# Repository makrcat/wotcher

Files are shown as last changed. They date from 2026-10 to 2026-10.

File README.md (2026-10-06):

## wotcher


wotcher is a digital raise-to-wake LED watch, with 89 LEDs in total! It uses something called charlieplexing to make all the lights glow at once. 

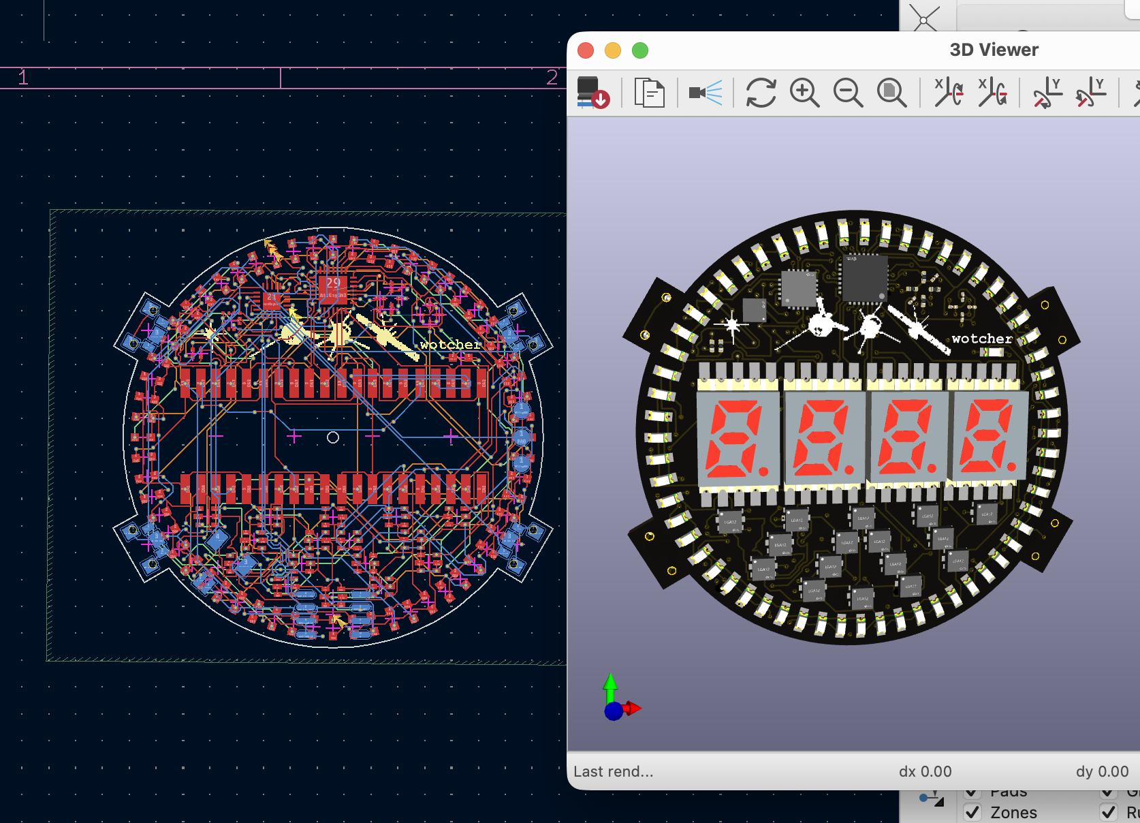
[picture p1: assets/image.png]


## circuit design
Charlieplexing is a method to limit current & control many LED's with only a couple of microcontroller pins, by switching between LEDs really fast so it looks like they're always on, due to the phenomenon of persistence of vision.

- My project uses a charlieplexing chip (IS31FL3731-QF) to drive the 7-segment display & all 60 LEDs, which is 88 LEDs in total. 
- The clock chip (DS3231MZ+) is necessary here because the ATtiny's internal RC oscillator clock is terrible at time keeping. The clock chip only drifts like 2 seconds a year! So that's cool.
- I'm also including an accelerometer so that it's raise-to-wake, like those Apple watches.

# some inspiration

It's inspired by various retro-style watches, such as the aptly named retrowatch, the charlie watch, and the decko circuit face watch, as well as other pinterest pictures.

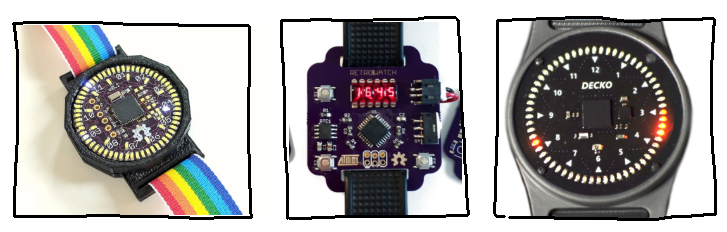
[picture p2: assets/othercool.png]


<i>from left to right, <a src="https://trmm.net/Charliewatch/">charliewatch</a>, <a src="https://github.com/RafaelRiber/RetroWatch">retrowatch</a>, decko (by the Terminelectro company)</i>

## features

I'm going to use embedded c++ to code this later, when I get my breadboard components.

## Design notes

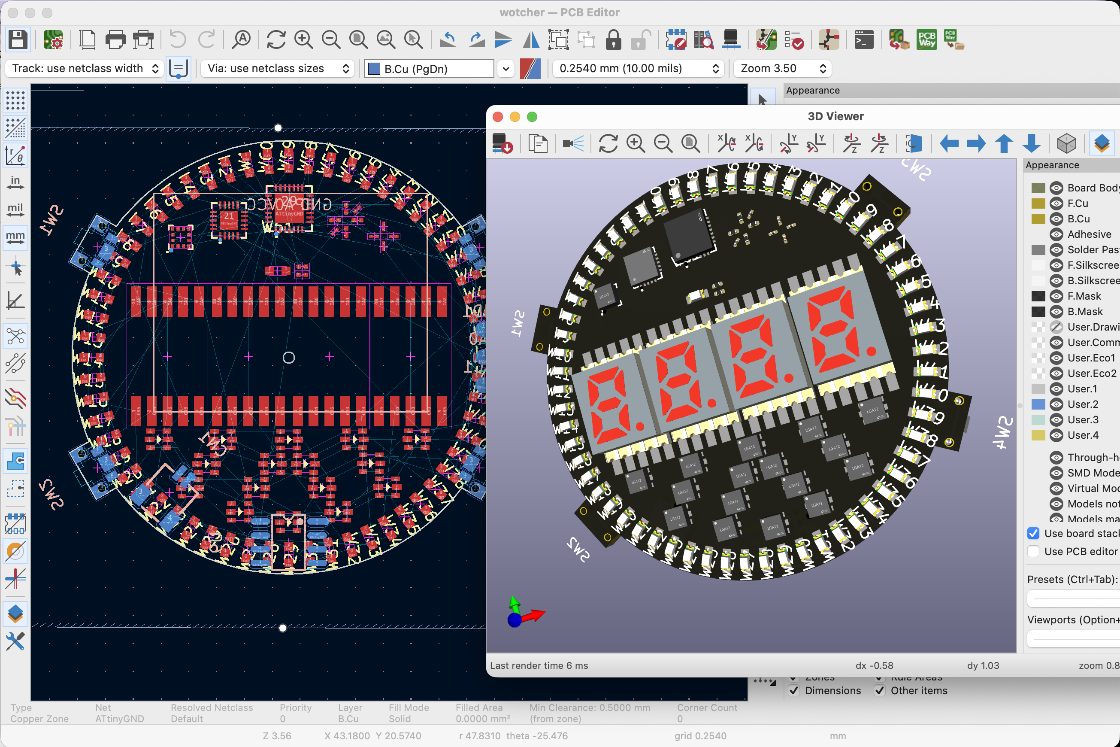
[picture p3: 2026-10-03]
assets/3ded.png

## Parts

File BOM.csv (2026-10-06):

Category | Item Name | Qty | Price (total) (USD) | Item link | Notes
Prototyping | LED Matrix | 1 | $7.50 | https://www.digikey.com/en/products/detail/adafruit-industries-llc/2947/5959341 | Buying an LED Matrix to prototype test the 60 LEDs
 | 3731 driver | 1 | $5.95 | https://www.digikey.com/en/products/detail/adafruit-industries-llc/2946/5959340
 | clock oscillator | 1 | $6.90 | https://www.dfrobot.com/product-1991.html | can I pay for shipping
 | ATtiny1616 breakout | 1 | $4.95 | https://www.digikey.com/en/products/detail/adafruit-industries-llc/5690/18627499?_gl=1*1cuqnpn*_up*MQ..*_gs*MQ..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 | breakout
 | 7-segment | 4 | $11.64 | https://www.digikey.com/en/products/detail/kingbright/ACSA02-41SURKWA-F01/2163665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..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 | through hole, it's not the same one but for testing
 | soldering paste for the bottom | 4 | $8.99 | https://www.amazon.com/Clean-Lead-Solder-Paste-Grams/dp/B017RTTR14 | for the bottom
 | pogo pin clip | 1 | $10.95 | https://www.digikey.com/en/products/detail/adafruit-industries-llc/5433/16584075
 | flux paste | 1 | $9.99 | https://www.amazon.com/Wonderway-Soldering-Electronics-CELLPHONE-Repairing/dp/B0BNKKRYK9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
JLCPCB assembly | everything assembly | 1 | $129.32 | $108.18+ $0.9153 * 5
 | Total Price (USD): | $196.19

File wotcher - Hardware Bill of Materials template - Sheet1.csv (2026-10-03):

Category | Item Name | Qty | Price (total) (USD) | Item link | Notes
Prototyping | LED Matrix | 1 | $7.50 | https://www.digikey.com/en/products/detail/adafruit-industries-llc/2947/5959341 | Buying an LED Matrix to prototype test the 60 LEDs
 | 3731 driver | 1 | $5.95 | https://www.digikey.com/en/products/detail/adafruit-industries-llc/2946/5959340
 | clock oscillator | 1 | $13.89 | https://www.dfrobot.com/product-1991.html | breakout for clock? the cheapest shipping also is 7 typically. so 6.9 + 6.99 ish
 | ATtiny1616 breakout | 1 | $4.95 | https://www.digikey.com/en/products/detail/adafruit-industries-llc/5690/18627499?_gl=1*1cuqnpn*_up*MQ..*_gs*MQ..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 | breakout
 | 7-segment | 4 | $11.64 | https://www.digikey.com/en/products/detail/kingbright/ACSA02-41SURKWA-F01/2163665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..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
 | soldering paste for the bottom | 4 | $8.99 | https://www.amazon.com/Clean-Lead-Solder-Paste-Grams/dp/B017RTTR14 | for the bottom
 | pogo pin clip | 1 | $10.95 | https://www.digikey.com/en/products/detail/adafruit-industries-llc/5433/16584075
 | flux paste | 1 | $9.99 | https://www.amazon.com/Wonderway-Soldering-Electronics-CELLPHONE-Repairing/dp/B0BNKKRYK9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
 | shipping | 1 | $6.00 |  | shipping of everything from digikey
 | soldering wire 1.5mm | 1 | $5.99 | amazon.com/Twocorn-no-wash-tin-Lead-Electric-Soldering/dp/B0CP7QHFL6/ref=sr_1_2?crid=3EKAVLY062JCC&dib=eyJ2IjoiMSJ9.747xCQO5tRRNg4I0eKnw59L2js-5auqvDzRBTbYA6CoUKzup8bUXZ3SKMNLic8xc0qTHKDJwwyOna-PWkxXdCCHtRuuMMQFeWQlOMeJixGyOjNt_YdHnpQc8tKk4BH70umB90eUAusJcc42KmHKfnX7hwkaPR9XoKCGnjF94Ad4wkr66Krc8tEyqt4xo3hwedYY0NPcA5R4NJapoKcibdCG7nRS468bnBLWuweMWQBEs6iX5GcCcY4QzgA81bf9TCktqZFXi5EwyQ2f2MZ2iK3HRmgPfGlbS2s4rQkbR2Ds.HrBcUUcsInr7EMFH0N10_6-wFEqmTffkIIklmmF6g24&dib_tag=se&keywords=soldering+wire+no+lead&qid=1791061150&refinements=p_36%3A-700&rnid=1243644011&sprefix=soldering+wire+no+lead%2Caps%2C156&sr=8-2
JLCPCB assembly | everything assembly | 1 | $112.76 | $108.18+ $0.9153 * 5
 | sanity
 | shipping | 1 | $6.00 |  | yet more shipping
 | Total Price (USD): | $204.61

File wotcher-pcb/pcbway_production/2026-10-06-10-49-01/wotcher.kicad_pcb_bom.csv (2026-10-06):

Designator | Quantity | Value | Footprint | Package | MPN | DNP | Mount_Type | Description | LCSC Part | Manufacturer | Sim.Pins
C1, C3, C4, C5, C6 | 5 | 0.1uF | C_01005_0402Metric |  |  |  | smt | Unpolarized capacitor, small symbol
C2 | 1 | 1uF | C_01005_0402Metric |  |  |  | smt | Unpolarized capacitor, small symbol
CN1 | 1 | SM02B-SRSS-TB | CONN-SMD_2P-P1.00_SM02B-SRSS-TB-LF-SN |  | SM02B-SRSS-TB(LF)(SN) |  | smt |  | C160402 | JST
D1, D10, D11, D12, D13, D14, D15, D16, D2, D3, D4, D5, D6, D7, D8, D9 | 16 | LED_RGB | LED-ARRAY-SMD_6P-L1.6-W1.6-TL_19-337C-RSBHGHC-M01 |  |  |  | tht | RGB LED, 6 pin package | C3019536
R1, R2, R3 | 3 | 4.7k | R_0201_0603Metric |  |  |  | smt | Resistor, small US symbol
R4 | 1 | 100k | R_0201_0603Metric |  |  |  | smt | Resistor, small US symbol
R5 | 1 | 20k | R_0201_0603Metric |  |  |  | smt | Resistor, small US symbol
R6 | 1 | 220 | R_0201_0603Metric |  |  |  | smt | Resistor, small US symbol
SW1, SW2, SW3, SW4 | 4 | SKTDLHE010 | KEY-SMD_SKTDLHE010 |  | SKTDLHE010 |  | smt |  | C380198 | ALPSALPINE(阿尔卑斯阿尔派)
U1, U2, U6, U8 | 4 | KCSA02-105 | KCSC02-105 |  |  |  | smt | One digit 7 segment hyper red LED, common anode
U3 | 1 | LIS2DW12TR-MS | LGA-12_L2.0-W2.0_BMA250 |  | LIS2DW12TR-MS |  | smt |  | C50385411 | MSKSEMI(美森科)
U5 | 1 | ATtiny1616-M | QFN-20_L3.0-W3.0-P0.40-BL-EP1.7 |  |  |  | smt |  | C507118
U7 | 1 | IS31FL3731-QF | QFN-28_L4.0-W4.0-P0.40-BL-EP |  | null |  | smt | 9x16 LED matrix driver with 8-bit PWM and breathing, QFN-28 | C191206 | null
U9 | 1 | DS3231MZ+ | SOIC-8_L4.9-W3.9-P1.27-LS6.0-BL |  | DS3231MZ+TRL |  | smt |  | C107410 | ADI(亚德诺)/MAXIM(美信)
W1, W10, W11, W12, W13, W14, W15, W16, W17, W18, W19, W2, W20, W21, W22, W23, W24, W25, W26, W27, W28, W29, W3, W30, W31, W32, W33, W34, W35, W36, W37, W38, W39, W4, W40, W41, W42, W43, W44, W45, W46, W47, W48, W49, W5, W50, W51, W52, W53, W54, W55, W56, W57, W58, W59, W6, W60, W61, W7, W8, W9 | 61 | LED_Small | LED-SMD_L1.6-W0.8-R-RD |  |  |  | smt | Light emitting diode, small symbol | C2286 |  | 1=K 2=A

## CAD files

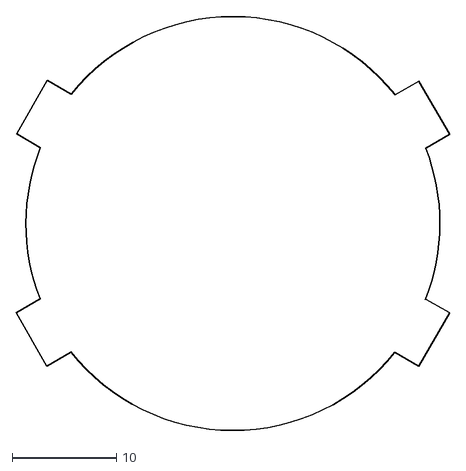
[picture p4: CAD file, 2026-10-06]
wotcher-pcb/edge-outline.dxf
41.6 x 39.8

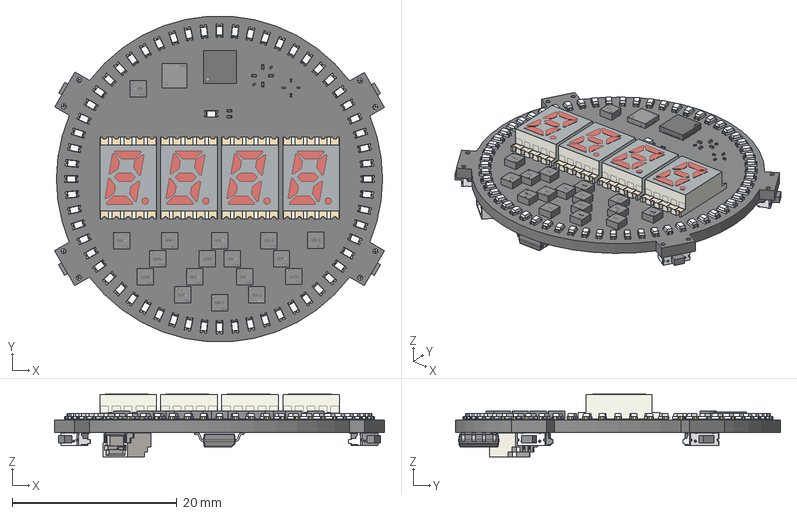
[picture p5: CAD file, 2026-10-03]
wotcher.step
40.1 x 39.5 x 7.63 mm
LED0603_L1.6-W0.8-H0.6 x 61
LGA-12_L2.0-W2.0-H1.0-P0.50 x 17
QFN-28_L4.0-W4.0-H0.9-P0.40-BL-EP
C_01005_0402Metric x 6
R_0201_0603Metric x 6
KCSC02-105 x 4
QFN-20_L3.0-W3.0-P0.40-BL-EP1.7
CONN-SMD_SR1.00-WS-2P
KEY-SMD_SKTDLHE010 x 4
SOIC-8_L4.9-W3.9-H1.7-LS6.0-P1.27
wotcher_PCB

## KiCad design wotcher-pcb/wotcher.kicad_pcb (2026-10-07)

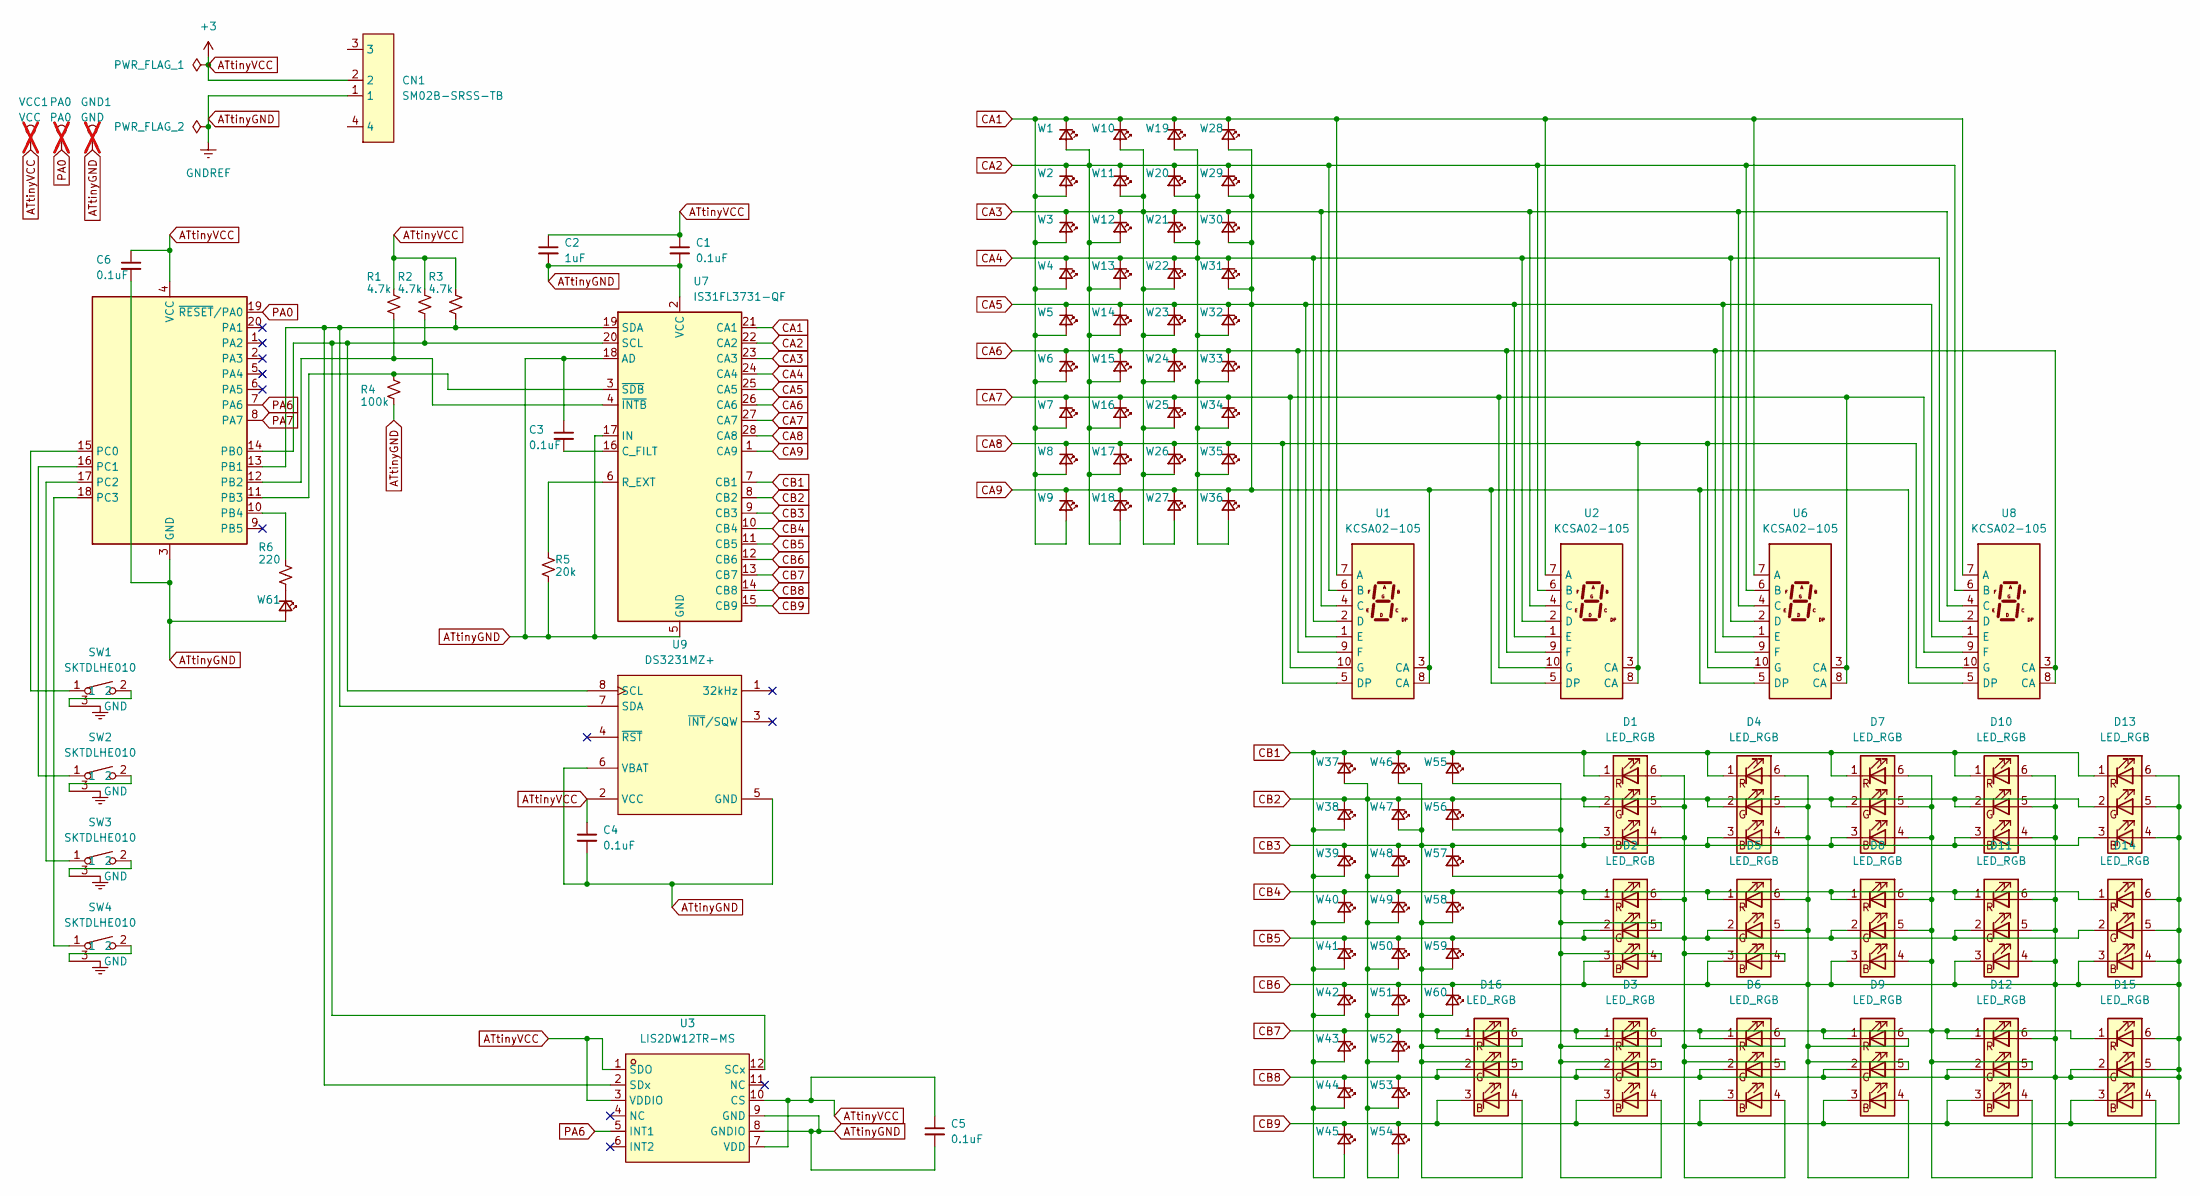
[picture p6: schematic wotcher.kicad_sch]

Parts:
C1, C3, C4, C5, C6: 0.1uF; C_01005_0402Metric
C2: 1uF; C_01005_0402Metric
CN1: SM02B-SRSS-TB; CONN-SMD_2P-P1.00_SM02B-SRSS-TB-LF-SN; MPN SM02B-SRSS-TB(LF)(SN); LCSC Part C160402
D1, D2, D3, D4, D5, D6, D7, D8, D9, D10, D11, D12, D13, D14, D15, D16: LED_RGB; LED-ARRAY-SMD_6P-L1.6-W1.6-TL_19-337C-RSBHGHC-M01
GND1: GND; TestPoint_Pad_D1.5mm; not fitted
PA0: PA0; TestPoint_Pad_D1.5mm; not fitted
R1, R2, R3: 4.7k; R_0201_0603Metric
R4: 100k; R_0201_0603Metric
R5: 20k; R_0201_0603Metric
R6: 220; R_0201_0603Metric
SW1, SW2, SW3, SW4: SKTDLHE010; KEY-SMD_SKTDLHE010; MPN SKTDLHE010; LCSC Part C380198
U1, U2, U6, U8: KCSA02-105; KCSC02-105
U3: LIS2DW12TR-MS; LGA-12_L2.0-W2.0_BMA250; MPN LIS2DW12TR-MS; LCSC Part C50385411
U5: ATtiny1616-M; QFN-20_L3.0-W3.0-P0.40-BL-EP1.7
U7: IS31FL3731-QF; QFN-28_L4.0-W4.0-P0.40-BL-EP
U9: DS3231MZ+; SOIC-8_L4.9-W3.9-P1.27-LS6.0-BL; MPN DS3231MZ+TRL; LCSC Part C107410
VCC1: VCC; TestPoint_Pad_D1.5mm; not fitted
W1, W2, W3, W4, W5, W6, W7, W8, W9, W10, W11, W12, W13, W14, W15, W16, W17, W18, W19, W20, W21, W22, W23, W24, W25, W26, W27, W28, W29, W30, W31, W32, W33, W34, W35, W36, W37, W38, W39, W40, W41, W42, W43, W44, W45, W46, W47, W48, W49, W50, W51, W52, W53, W54, W55, W56, W57, W58, W59, W60, W61: LED_Small; LED-SMD_L1.6-W0.8-R-RD

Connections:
ATtinyGND: C1.2, C2.2, C3.1, C4.2, C5.2, C6.2, CN1.1, GND1.1, R4.2, R5.2, U3.8 (GNDIO), U3.9 (GND), U5.3 (GND), U5.21 (GND), U7.2 (VCC), U7.5 (GND), U7.17 (IN), U7.18 (AD), U7.29 (GND), U9.5 (GND), U9.6 (VBAT), W61.2 (A)
ATtinyVCC: C1.1, C2.1, C4.1, C5.1, C6.1, CN1.2, R1.1, R2.1, R3.1, U3.1 (SDO), U3.3 (VDDIO), U3.7 (VDD), U3.10 (CS), U5.4 (VCC), U9.2 (VCC), VCC1.1
CA1: U1.7 (A), U2.7 (A), U6.7 (A), U7.21 (CA1), U8.7 (A), W1.1 (K), W2.2 (A), W3.2 (A), W4.2 (A), W5.2 (A), W6.2 (A), W7.2 (A), W8.2 (A), W9.2 (A), W10.1 (K), W19.1 (K), W28.1 (K)
CA2: U1.6 (B), U2.6 (B), U6.6 (B), U7.22 (CA2), U8.6 (B), W1.2 (A), W2.1 (K), W11.1 (K), W12.2 (A), W13.2 (A), W14.2 (A), W15.2 (A), W16.2 (A), W17.2 (A), W18.2 (A), W20.1 (K), W29.1 (K)
CA3: U1.4 (C), U2.4 (C), U6.4 (C), U7.23 (CA3), U8.4 (C), W3.1 (K), W10.2 (A), W11.2 (A), W12.1 (K), W21.1 (K), W22.2 (A), W23.2 (A), W24.2 (A), W25.2 (A), W26.2 (A), W27.2 (A), W30.1 (K)
CA4: U1.2 (D), U2.2 (D), U6.2 (D), U7.24 (CA4), U8.2 (D), W4.1 (K), W13.1 (K), W19.2 (A), W20.2 (A), W21.2 (A), W22.1 (K), W31.1 (K), W32.2 (A), W33.2 (A), W34.2 (A), W35.2 (A), W36.2 (A)
CA5: U1.1 (E), U1.3 (CA), U1.8 (CA), U2.1 (E), U2.5 (DP), U6.1 (E), U6.5 (DP), U7.1 (CA9), U7.25 (CA5), U8.1 (E), U8.5 (DP), W5.1 (K), W9.1 (K), W14.1 (K), W18.1 (K), W23.1 (K), W27.1 (K), W28.2 (A), W29.2 (A), W30.2 (A), W31.2 (A), W32.1 (K), W36.1 (K)
CA6: U1.9 (F), U2.9 (F), U6.9 (F), U7.26 (CA6), U8.3 (CA), U8.8 (CA), W6.1 (K), W15.1 (K), W24.1 (K), W33.1 (K)
CA7: U1.10 (G), U2.10 (G), U6.3 (CA), U6.8 (CA), U7.27 (CA7), U8.9 (F), W7.1 (K), W16.1 (K), W25.1 (K), W34.1 (K)
CA8: U1.5 (DP), U2.3 (CA), U2.8 (CA), U6.10 (G), U7.28 (CA8), U8.10 (G), W8.1 (K), W17.1 (K), W26.1 (K), W35.1 (K)
CB1: D1.1 (RK), D4.1 (RK), D7.1 (RK), D10.1 (RK), D13.1 (RK), U7.7 (CB1), W37.1 (K), W38.2 (A), W39.2 (A), W40.2 (A), W41.2 (A), W42.2 (A), W43.2 (A), W44.2 (A), W45.2 (A), W46.1 (K), W55.1 (K)
CB2: D1.2 (GK), D4.2 (GK), D7.2 (GK), D10.2 (GK), D13.2 (GK), U7.8 (CB2), W37.2 (A), W38.1 (K), W47.1 (K), W48.2 (A), W49.2 (A), W50.2 (A), W51.2 (A), W52.2 (A), W53.2 (A), W54.2 (A), W56.1 (K)
CB3: D1.3 (BK), D4.3 (BK), D7.3 (BK), D10.3 (BK), D13.3 (BK), D16.4 (BA), D16.5 (GA), D16.6 (RA), U7.9 (CB3), W39.1 (K), W46.2 (A), W47.2 (A), W48.1 (K), W57.1 (K), W58.2 (A), W59.2 (A), W60.2 (A)
CB4: D2.1 (RK), D2.4 (BA), D2.5 (GA), D3.4 (BA), D3.5 (GA), D3.6 (RA), D5.1 (RK), D8.1 (RK), D11.1 (RK), D14.1 (RK), U7.10 (CB4), W40.1 (K), W49.1 (K), W55.2 (A), W56.2 (A), W57.2 (A), W58.1 (K)
CB5: D1.4 (BA), D1.5 (GA), D1.6 (RA), D2.2 (GK), D2.6 (RA), D5.2 (GK), D5.4 (BA), D6.4 (BA), D6.5 (GA), D6.6 (RA), D8.2 (GK), D11.2 (GK), D14.2 (GK), U7.11 (CB5), W41.1 (K), W50.1 (K), W59.1 (K)
CB6: D2.3 (BK), D3.2 (GK), D3.3 (BK), D4.4 (BA), D4.5 (GA), D4.6 (RA), D5.3 (BK), D5.5 (GA), D5.6 (RA), D6.2 (GK), D6.3 (BK), D8.3 (BK), D9.2 (GK), D9.3 (BK), D9.4 (BA), D9.5 (GA), D9.6 (RA), D10.4 (BA), D10.5 (GA), D10.6 (RA), D11.3 (BK), D11.4 (BA), D11.5 (GA), D11.6 (RA), D12.2 (GK), D12.3 (BK), D12.6 (RA), D13.4 (BA), D13.5 (GA), D13.6 (RA), D14.3 (BK), D14.4 (BA), D14.5 (GA), D14.6 (RA), D15.2 (GK), D15.3 (BK), D15.4 (BA), D15.5 (GA), D15.6 (RA), D16.2 (GK), D16.3 (BK), U7.12 (CB6), U7.14 (CB8), U7.15 (CB9), W42.1 (K), W44.1 (K), W45.1 (K), W51.1 (K), W53.1 (K), W54.1 (K), W60.1 (K)
CB7: D3.1 (RK), D6.1 (RK), D7.4 (BA), D7.5 (GA), D7.6 (RA), D8.4 (BA), D8.5 (GA), D8.6 (RA), D9.1 (RK), D12.1 (RK), D12.4 (BA), D12.5 (GA), D15.1 (RK), D16.1 (RK), U7.13 (CB7), W43.1 (K), W52.1 (K)
unnamed: SW1.2, SW1.3 (GND)
unnamed: SW2.2, SW2.3 (GND)
unnamed: SW3.2, SW3.3 (GND)
unnamed: SW4.2, SW4.3 (GND)
unnamed: R2.2, U3.12 (SCx), U5.14 (PB0), U7.20 (SCL), U9.8 (SCL)
unnamed: R3.2, U3.2 (SDx), U5.13 (PB1), U7.19 (SDA), U9.7 (SDA)
unnamed: R1.2, U5.12 (PB2), U7.4 (~INTB)
unnamed: R4.1, U5.11 (PB3), U7.3 (~SDB)
unnamed: R6.1, U5.10 (PB4)
unnamed: SW1.1, U5.15 (PC0)
unnamed: SW2.1, U5.16 (PC1)
unnamed: SW3.1, U5.17 (PC2)
unnamed: SW4.1, U5.18 (PC3)
unnamed: C3.2, U7.16 (C_FILT)
unnamed: R5.1, U7.6 (R_EXT)
unnamed: R6.2, W61.1 (K)
PA0: PA0.1, U5.19 (~RESET/PA0)
PA6: U3.5 (INT1), U5.7 (PA6)
PA7: U5.8 (PA7)

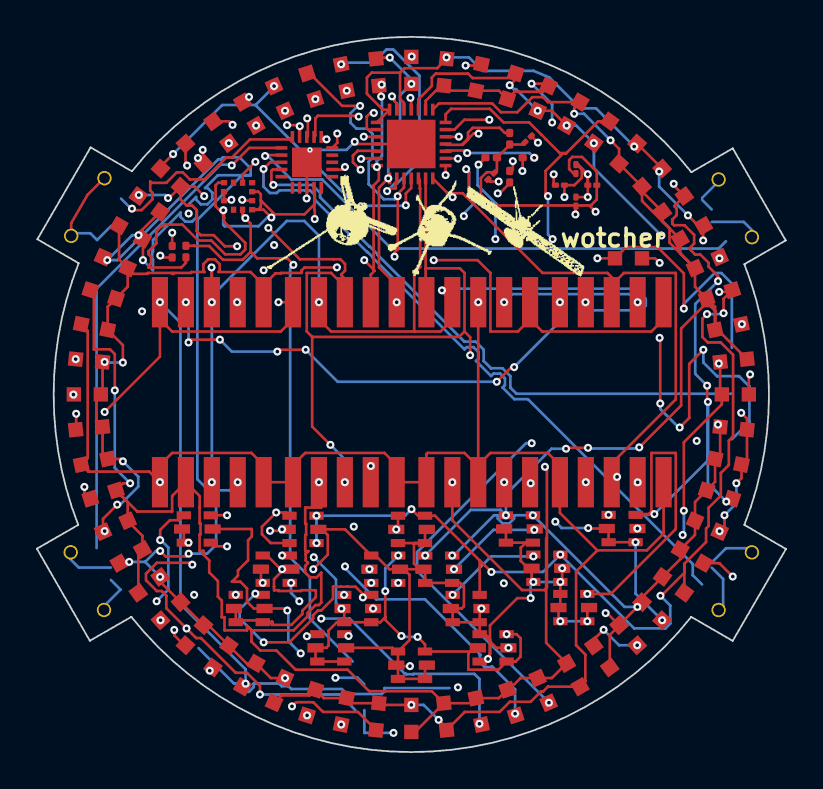
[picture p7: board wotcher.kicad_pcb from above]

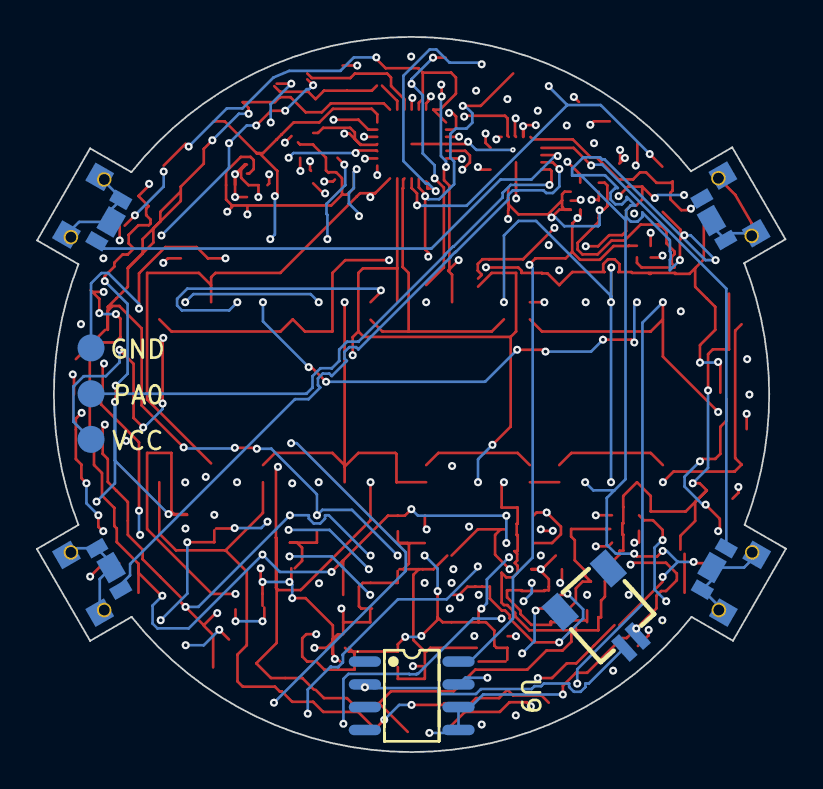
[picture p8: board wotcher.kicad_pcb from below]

Board: 4 copper layers, 41.6 x 39.7 mm, 105 parts (9 on the bottom side), 35 nets.

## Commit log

2026-10-03 switch files around, add BOM and stuff
    [ouuuuu.dxf, wotcher - Hardware Bill of Materials template - Sheet1.csv, wotcher.kicad_pcb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]
2026-10-03 added 3D model
    [wotcher.kicad_pcb, wotcher.kicad_sch, wotcher.step]
2026-10-06 add step file
    [edge-outline.dxf, wotcher.kicad_pcb, wotcher.kicad_pcb_bom.csv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]
2026-10-06 update BOM
    [BOM.csv]
2026-10-06 add a copper pour
    [wotcher.kicad_pcb]
2026-10-06 re-wired something
    [wotcher.kicad_pcb, wotcher.kicad_sch]
2026-10-06 no more bitmap D:
    [wotcher.kicad_pcb]
2026-10-06 remove backups, and update board again
    [ouuuuu.dxf, wotcher.kicad_pcb]
